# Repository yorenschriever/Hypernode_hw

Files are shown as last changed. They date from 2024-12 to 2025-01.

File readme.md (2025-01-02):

# HyperNode

HyperNode is a distribution node for 
[Hyperion](https://github.com/yorenschriever/Hyperion2). You can use this device to connect up to 8 led strips and 1 DMX universe. 

The device is based on the WT32-ETH01. The pcbs are made with AutoDesk Eagle. 

# BOM

|Amount|Name|Type|Value|Size|Price|Link|
|-|-|-|-|-|-|-|
|1|Controller||WT32-ETH01||||
|1|Line driver||74HCT245D|SO20W||
|1|DMX transceiver|MAX488||SOIC-8||
|2|Decoupling capacitor|Ceramic capacitor|100 nF|0603||
|10|Protection resistor|Thin film resistor|100 Ohm|0603||
|3|RJ45 Connectors|||||
|2|Resistor for led|Resistor|180 Ohm|0603|||
|2|Status and power led|SMD LED|Red|0603|||
|1|Power supply cap|Tantalum Capacitor|470 uF|D Type||
|1|Rectifier diode|||SMB||
|1|Step down module|||||
|1|JST XH connector M+F|2 Pin||||
|1|DC Barrel connector|2.1 x 5.5mm||||

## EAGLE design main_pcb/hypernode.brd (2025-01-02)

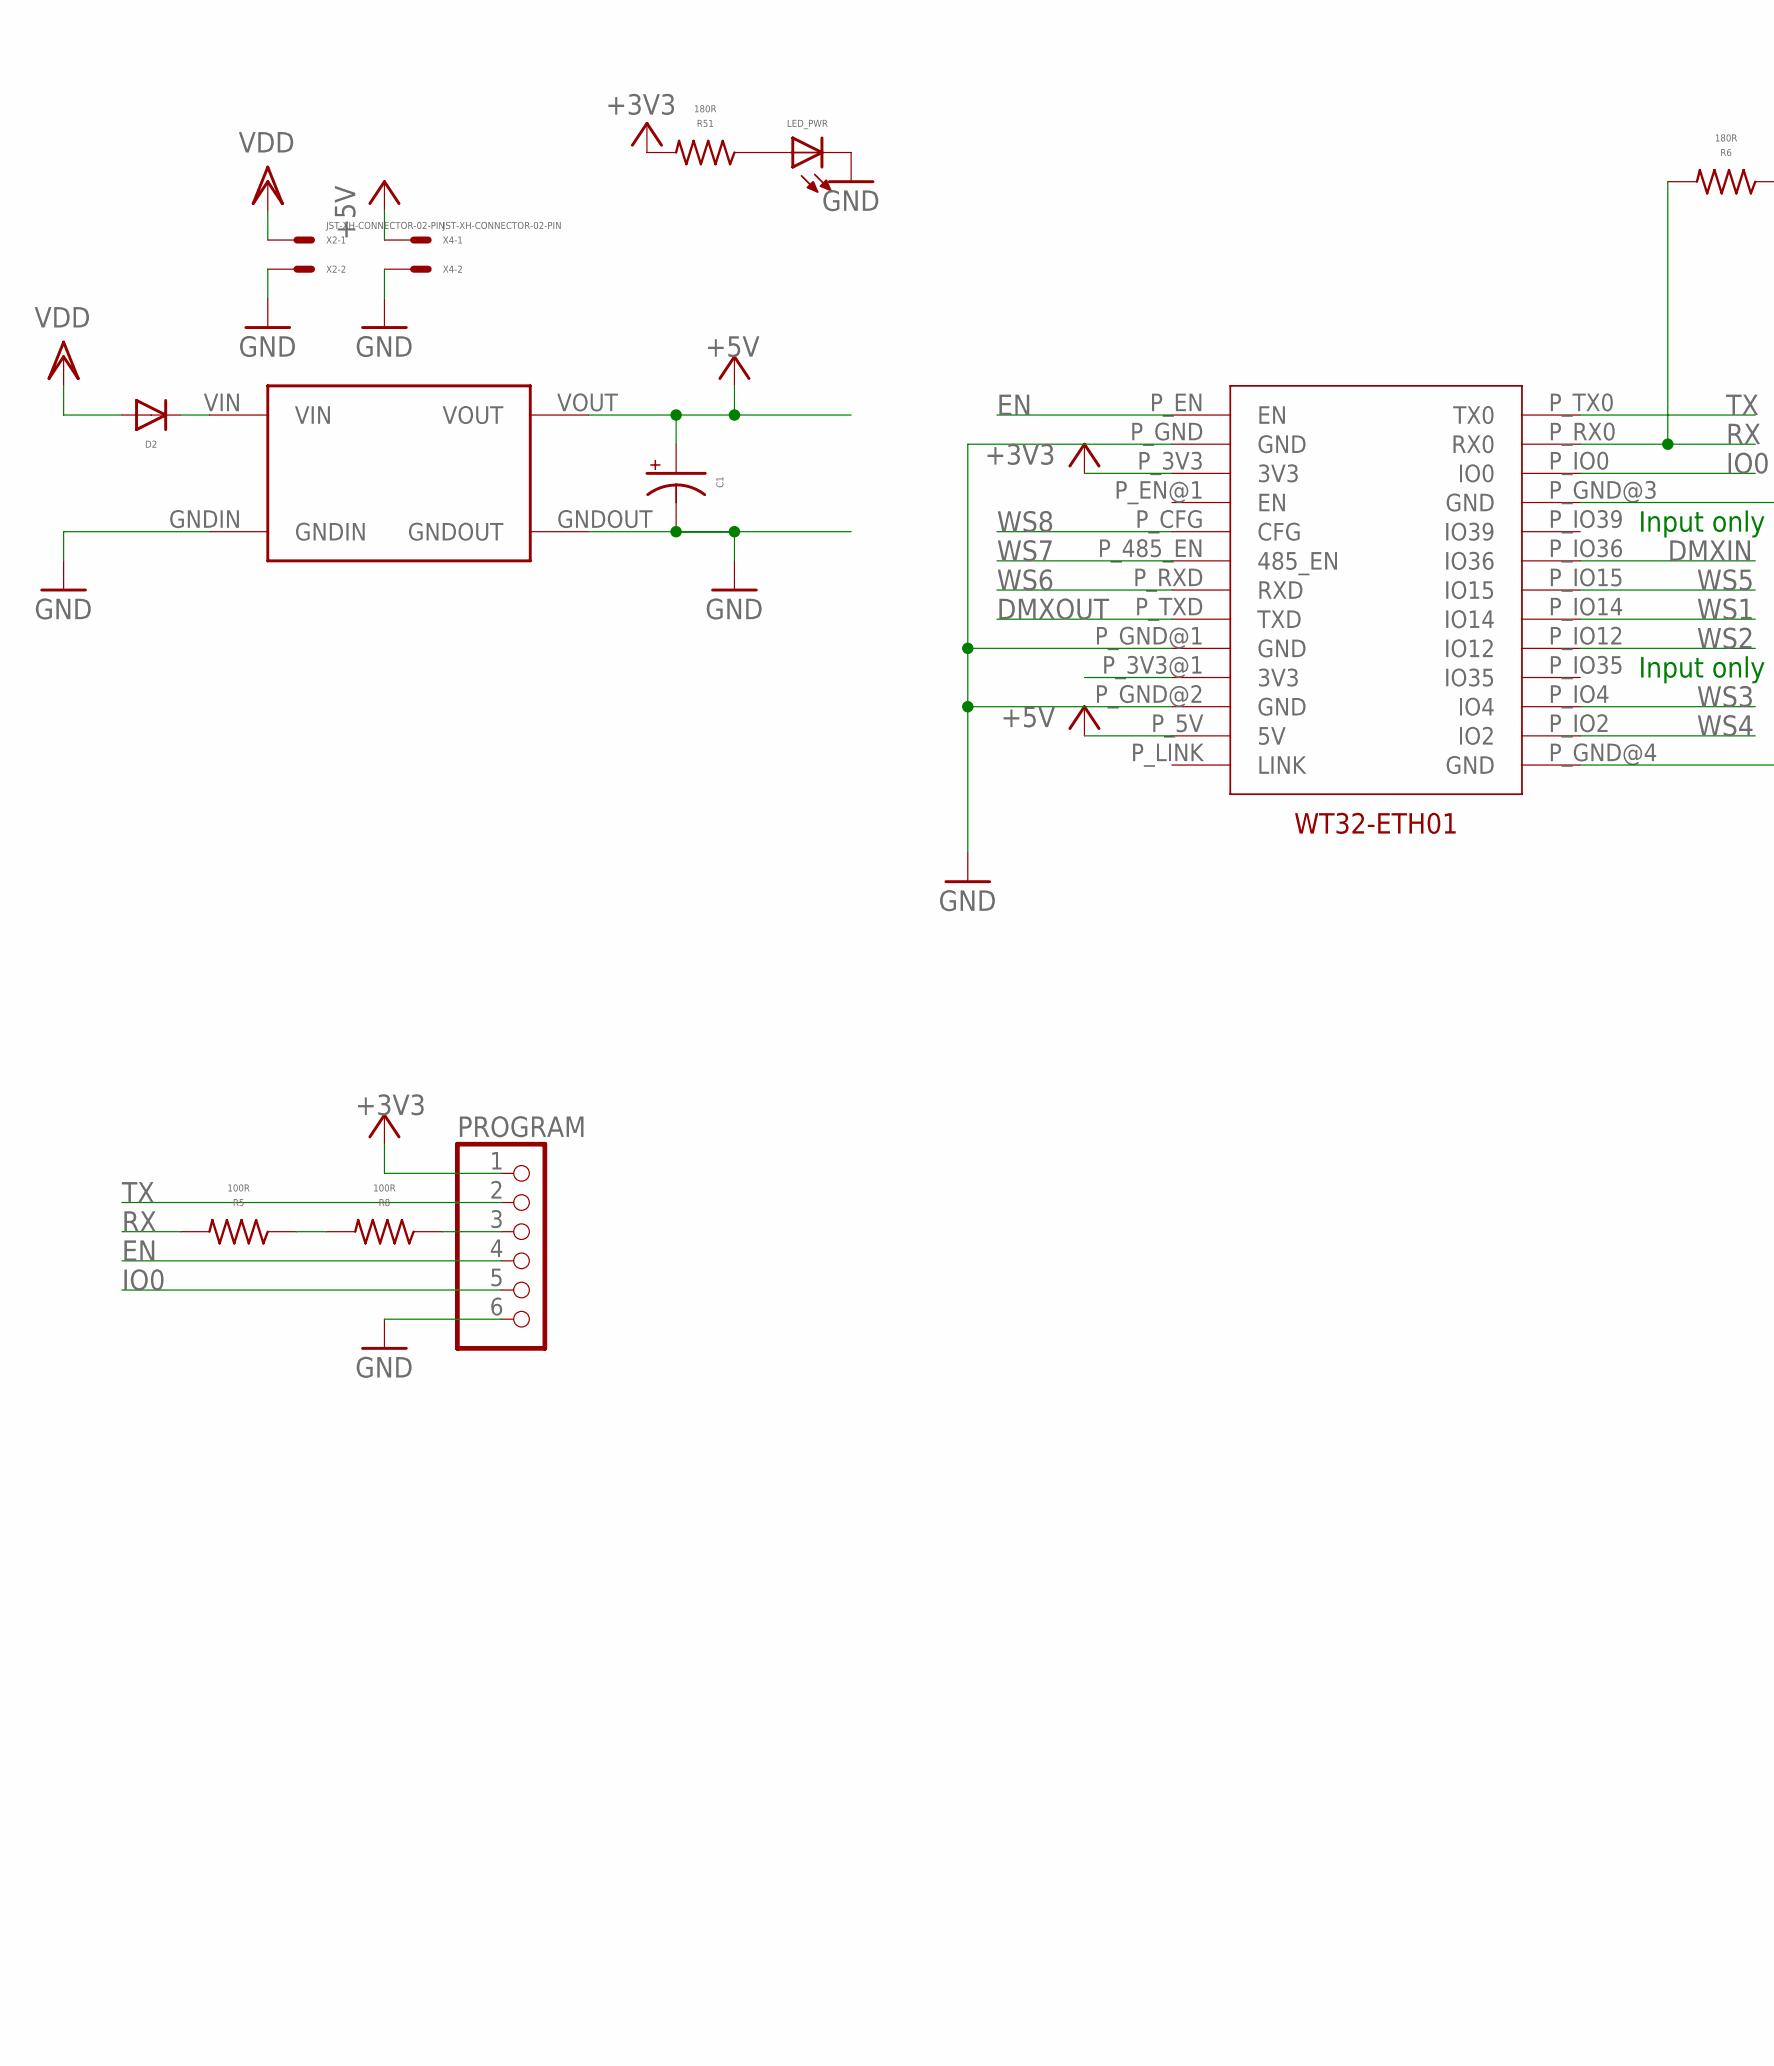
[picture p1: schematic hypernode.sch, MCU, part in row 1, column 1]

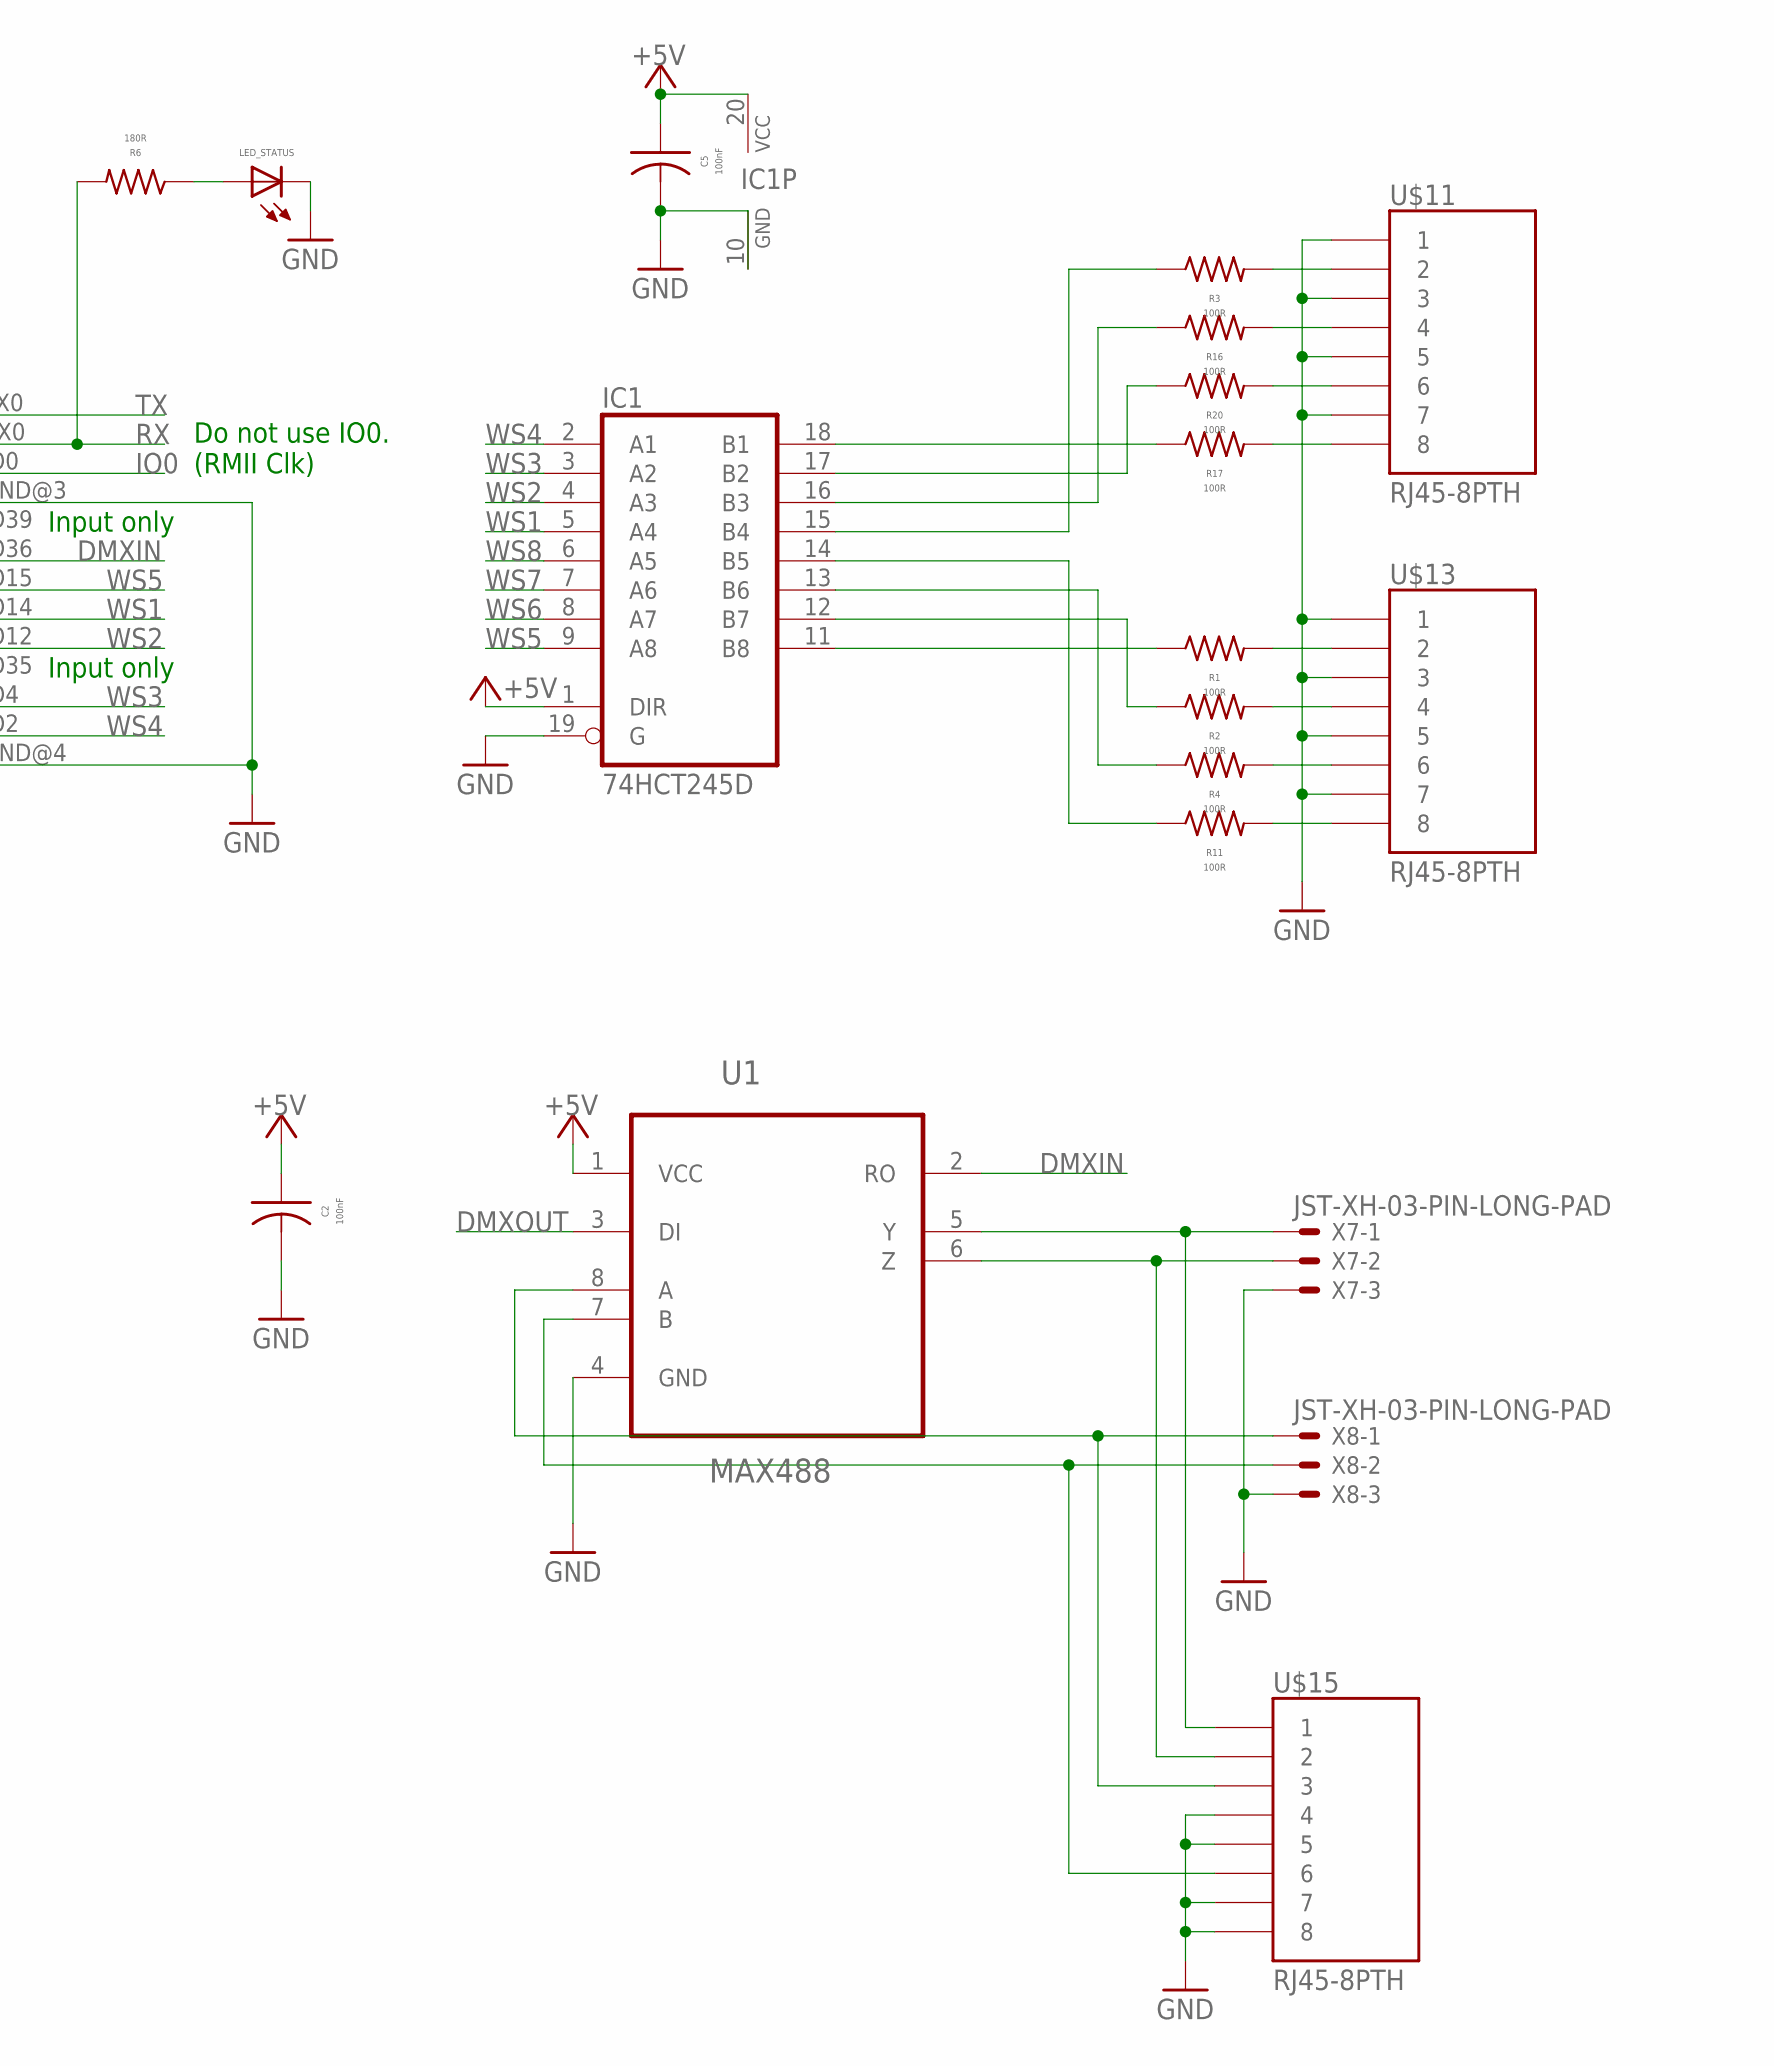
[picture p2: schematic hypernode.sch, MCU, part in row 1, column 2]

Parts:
C1: CAPACITOR_SMC-D; RCL_SMC_D
C2, C5: 100nF; ADAFRUIT_C0603
D2: DIODE_SMB
IC1: 74HCT245D; SO20W
LED_PWR: LED0603; ADAFRUIT_CHIPLED_0603
LED_STATUS: LED0603; ADAFRUIT_CHIPLED_0603
PROGRAM: PINHD-1X6; 1X06
R1, R2, R3, R4, R5, R8, R11, R16, R17, R20: 100R; ADAFRUIT_R0603
R6, R51: 180R; ADAFRUIT_R0603
U1: MAX488; SOIC127P600X175-8N
U$3: STEPDOWNMODULE; STEPDOWN_MODULE
U$11, U$13, U$15: RJ45-8PTH; RJ45-8
U$17: WT32-ETH01WT32-ETH01-SMD; WT32-ETH01-SMD
X2, X4: JST-XH-CONNECTOR-02-PIN; REMBRANDT-ELECTRONICS---JST-XH-CONNECTORS-V1-0_JST-XH-02-PA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
X7, X8: JST-XH-03-PIN-LONG-PAD; JST-XH-03-PACKAGE-LONG-PAD

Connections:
+3V3: PROGRAM.1, R51.2, U$17.P_3V3 (3V3)
+5V: C1.+, C2.1, C5.1, IC1.1 (DIR), IC1.20 (VCC), U1.1 (VCC), U$3.VOUT, U$17.P_5V (5V), X4.1
DMXA: U1.8 (A), U$15.3, X8.1
DMXB: U1.7 (B), U$15.6, X8.2
DMXIN: U1.2 (RO), U$17.P_IO36 (IO36)
DMXOUT: U1.3 (DI), U$17.P_TXD (TXD)
DMXY: U1.5 (Y), U$15.1, X7.1
DMXZ: U1.6 (Z), U$15.2, X7.2
EN: PROGRAM.4, U$17.P_EN (EN)
GND: C1.-, C2.2, C5.2, IC1.10 (GND), IC1.19 (G), LED_PWR.C, LED_STATUS.C, PROGRAM.6, U1.4 (GND), U$3.GNDIN, U$3.GNDOUT, U$11.1, U$11.3, U$11.5, U$11.7, U$13.1, U$13.3, U$13.5, U$13.7, U$15.4, U$15.5, U$15.7, U$15.8, U$17.P_GND (GND), U$17.P_GND@1 (GND), U$17.P_GND@2 (GND), U$17.P_GND@3 (GND), U$17.P_GND@4 (GND), X2.2, X4.2, X7.3, X8.3
IO0: PROGRAM.5, U$17.P_IO0 (IO0)
unnamed: R5.1, R8.2
unnamed: LED_STATUS.A, R6.1
unnamed: R3.2, U$11.2
unnamed: D2.C, U$3.VIN
unnamed: R16.2, U$11.4
unnamed: R20.2, U$11.6
unnamed: R17.2, U$11.8
unnamed: R1.2, U$13.2
unnamed: IC1.18 (B1), R17.1
unnamed: R2.2, U$13.4
unnamed: IC1.17 (B2), R20.1
unnamed: IC1.16 (B3), R16.1
unnamed: IC1.15 (B4), R3.1
unnamed: IC1.14 (B5), R11.1
unnamed: IC1.13 (B6), R4.1
unnamed: IC1.12 (B7), R2.1
unnamed: IC1.11 (B8), R1.1
unnamed: R4.2, U$13.6
unnamed: R11.2, U$13.8
unnamed: PROGRAM.3, R8.1
unnamed: LED_PWR.A, R51.1
RX: R5.2, R6.2, U$17.P_RX0 (RX0)
TX: PROGRAM.2, U$17.P_TX0 (TX0)
VDD: D2.A, X2.1
WS1: IC1.5 (A4), U$17.P_IO14 (IO14)
WS2: IC1.4 (A3), U$17.P_IO12 (IO12)
WS3: IC1.3 (A2), U$17.P_IO4 (IO4)
WS4: IC1.2 (A1), U$17.P_IO2 (IO2)
WS5: IC1.9 (A8), U$17.P_IO15 (IO15)
WS6: IC1.8 (A7), U$17.P_RXD (RXD)
WS7: IC1.7 (A6), U$17.P_485_EN (485_EN)
WS8: IC1.6 (A5), U$17.P_CFG (CFG)

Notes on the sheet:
Do not use IO0. (RMII Clk)
Input only

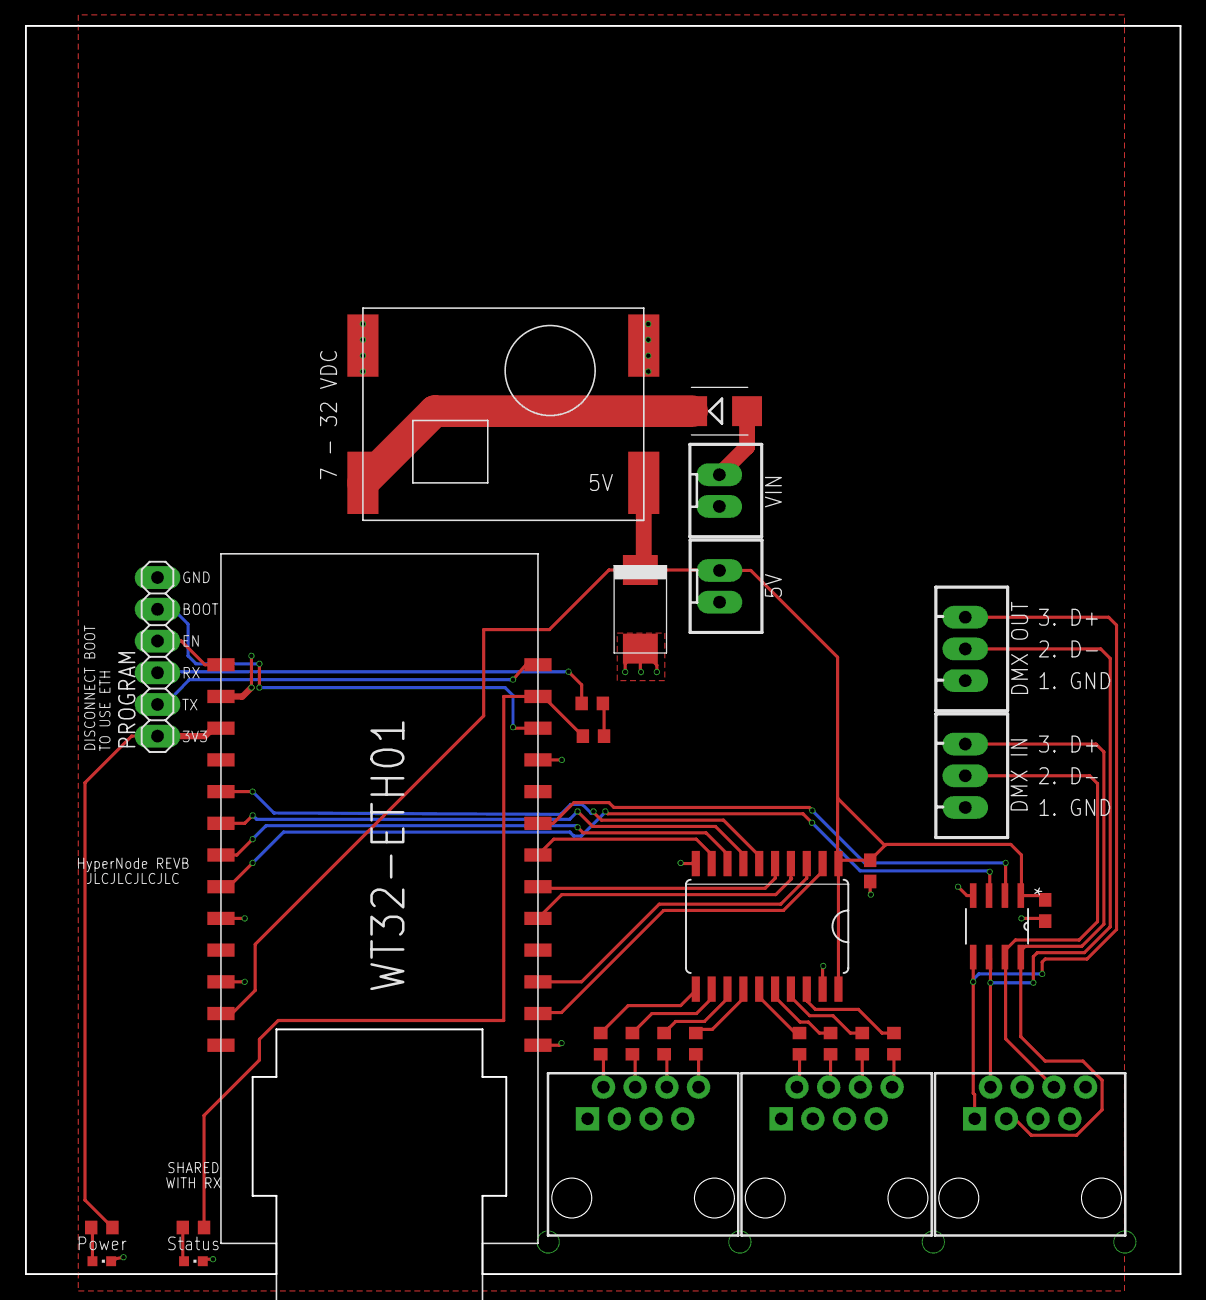
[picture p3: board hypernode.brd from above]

Board: 2 copper layers, 92.5 x 100.0 mm, 31 parts (0 on the bottom side), 43 nets.

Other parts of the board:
U$4: MULTISCHRIEVERLOGO_SOLDERMASK

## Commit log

2024-12-16 commit copy of etherledesp32pcb_v22_fixes_after_revc as starting point
    [hypernode.brd, hypernode.sch]
2024-12-16 remove unnecessary components from main pcb
    [hypernode.brd, hypernode.sch]
2024-12-17 further cleanup and arrangement
    [hypernode.brd, hypernode.sch]
2024-12-21 copy fornt panel from hyperion
    [frontpanel.brd, frontpanel.sch, hypernode.brd]
2024-12-21 front panel initial modifications
    [frontpanel.brd, frontpanel.sch, hypernode.brd]
2024-12-22 measurements before origin move
    [frontpanel.brd, hypernode.brd]
2024-12-22 move origin
    [hypernode.brd]
2024-12-22 align front panel
    [frontpanel.brd, hypernode.brd]
2024-12-22 rev A
    [frontpanel.brd, hypernode.brd, hypernode.sch]
2024-12-31 fix boot connetion
    [hypernode.brd, hypernode.sch]
2024-12-31 move wrt32 away from ws2812 ports
    [frontpanel.brd, hypernode.brd]
2024-12-31 DRC and cleanup
    [hypernode.brd]
2024-12-31 tented vias
    [hypernode.brd]
2025-01-02 change rx resistor to 2x100r
    [hypernode.brd, hypernode.sch]
2025-01-02 remove unnecessary pull down resistor
    [hypernode.brd, hypernode.sch]
2025-01-02 feed power led from 3v3
    [hypernode.brd, hypernode.sch]

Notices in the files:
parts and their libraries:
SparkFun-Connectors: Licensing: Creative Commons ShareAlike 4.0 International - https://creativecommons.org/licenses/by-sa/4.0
